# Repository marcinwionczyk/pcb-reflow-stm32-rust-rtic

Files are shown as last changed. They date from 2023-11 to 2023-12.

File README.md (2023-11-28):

# pcb-reflow-stm32-rust-rtic
This is how the reflow process look like:
https://youtu.be/pWV79pceqmc?si=kS1UuS4xw2wpDsws

## Software

Rust code for STM32F411RCT6 microcontroller to drive PCB reflow solder plate.
Code is based on https://github.com/gabrielvegamotta/PCB-Reflow/blob/main/V1-Arduino-PTH/Firmware/PCB_Reflow_V1.6.ino

Base of the code was generated with command: 
`cargo generate --git https://github.com/burrbull/stm32-template/`

In order to build it, you need to prepare your environment according to:
https://docs.rust-embedded.org/book/intro/install.html

and issue a command within this folder:
- `cargo build --release` for release version
- `cargo build` for unoptimised, debug version

Then you may run software on microcontroller with `cargo run` and flash it via STLink device with 
`cargo flash --release --chip STM32F411RCT6x`  
## Hardware
This is how the PCB top layer look like:
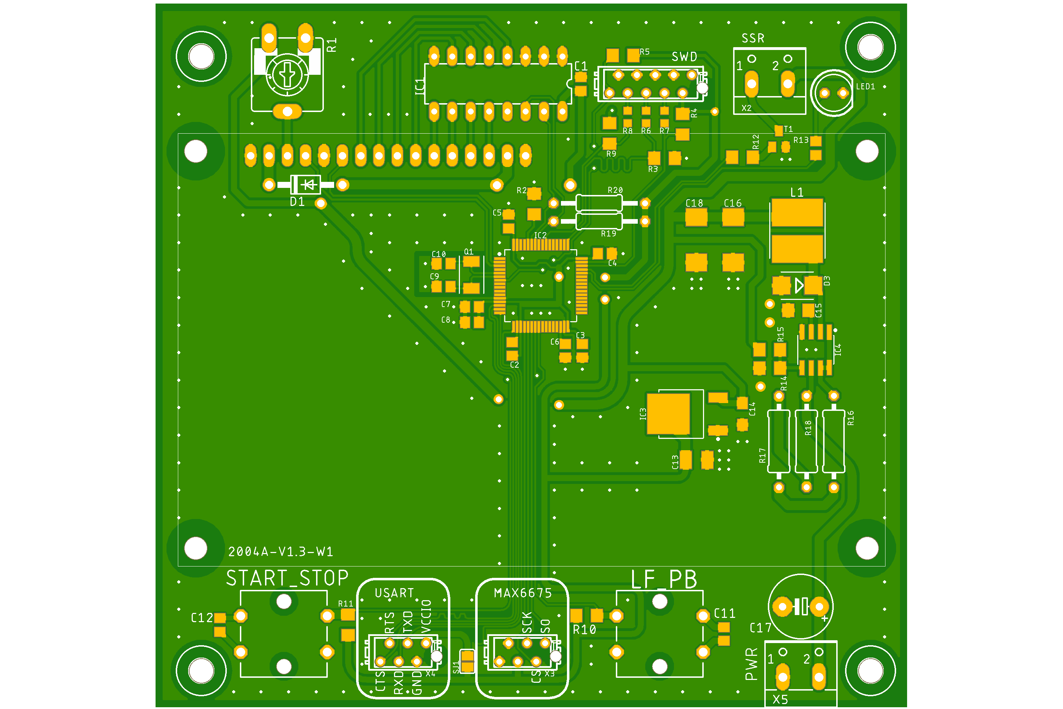
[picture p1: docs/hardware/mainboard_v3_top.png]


Here you have [schematics in PDF](./docs/hardware/mainboard_v3.pdf)

Some major parts:
1. MAX6675 as a temperature sensor. You can get it for example from here:
https://botland.store/high-precision-temperature-sensors/12504-max6675-thermocouple-spi-temperature-sensor-5904422307868.html
2. TC2004A LCD Character screen: https://botland.store/alphanumeric-and-graphic-displays/19736-lcd-display-4x20-characters-green-with-connectors-justpi-5903351243087.html
3. PCF8574 as I2C port expander
4. SWT-11136 buttons: https://botland.store/tact-switch/11138-tact-switch-12x12mm-cap-black-5-pieces-5904422307530.html
5. 
6. micromatch connectors (I have plenty of them)

PCB was designed with Autodesk EAGLE. 
- [schematics](./docs/hardware/mainboard_v3.sch)
- [PCB project](./docs/hardware/mainboard_v3.brd)

I power it with +12V DC.
If you want to order a PCB, here you have [gerber files](./docs/hardware/mainboard_v3_2023-11-27.zip)

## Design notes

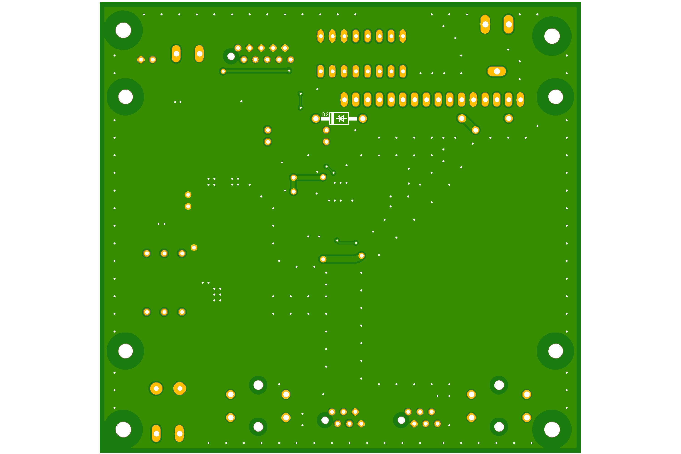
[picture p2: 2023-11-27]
docs/hardware/mainboard_v3_bottom.png

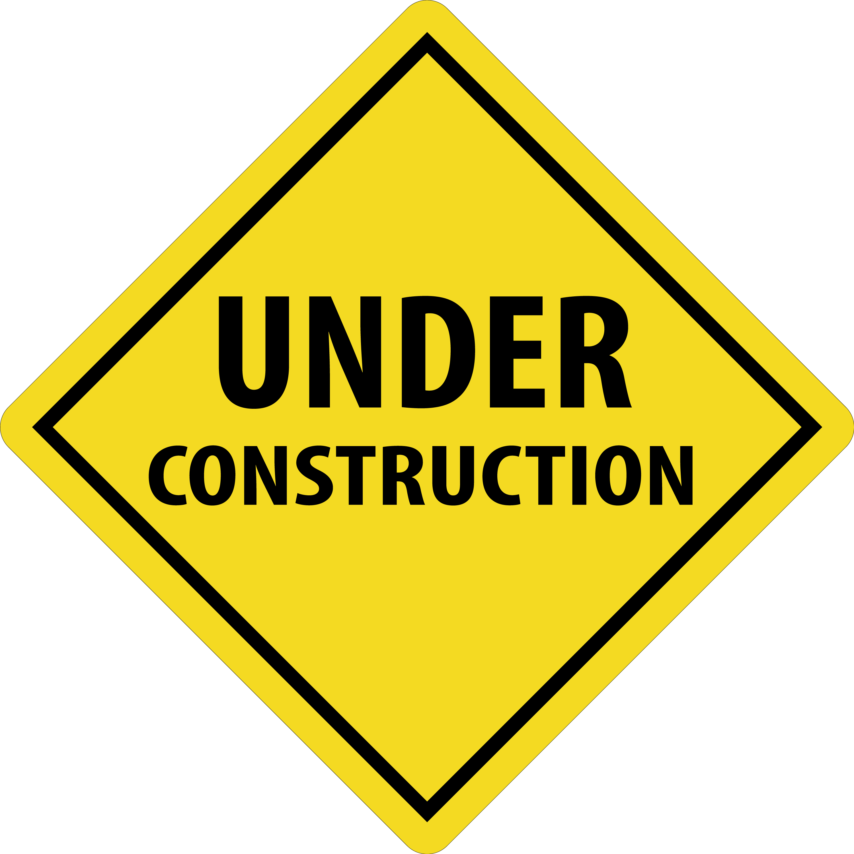
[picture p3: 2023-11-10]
docs/images/vectorstock_19719079.png

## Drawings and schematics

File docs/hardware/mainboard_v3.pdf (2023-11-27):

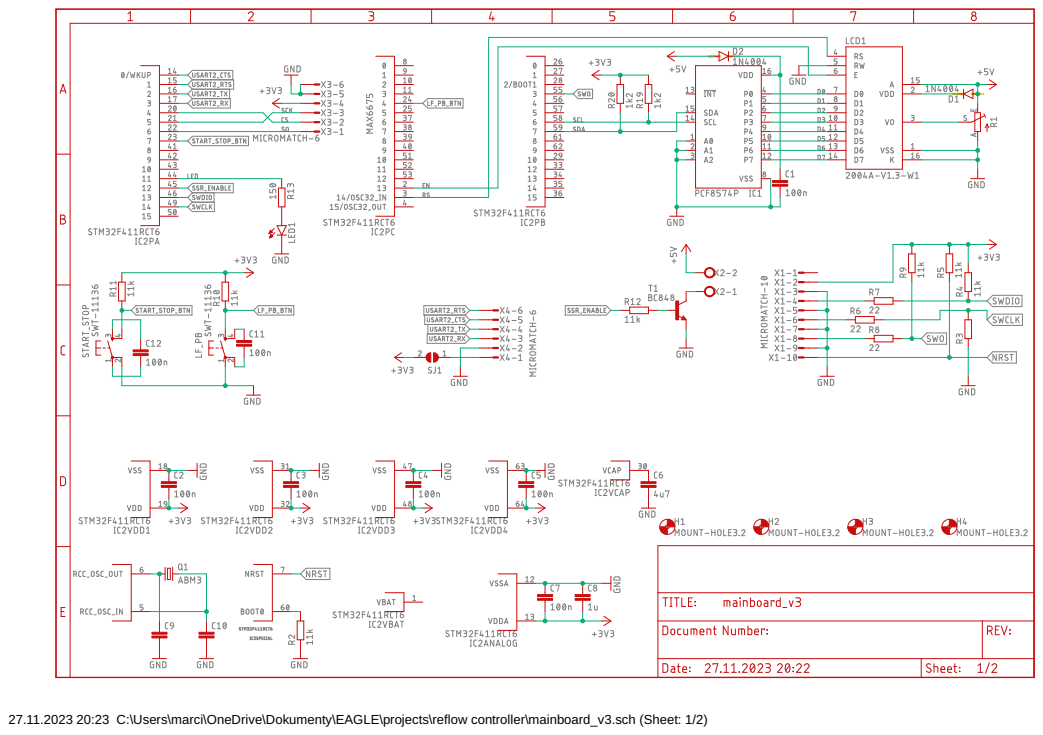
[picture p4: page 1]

27.11.2023 20:23 C:\Users\marci\OneDrive\Dokumenty\EAGLE\projects\reflow controller\mainboard_v3.sch (Sheet: 1/2)

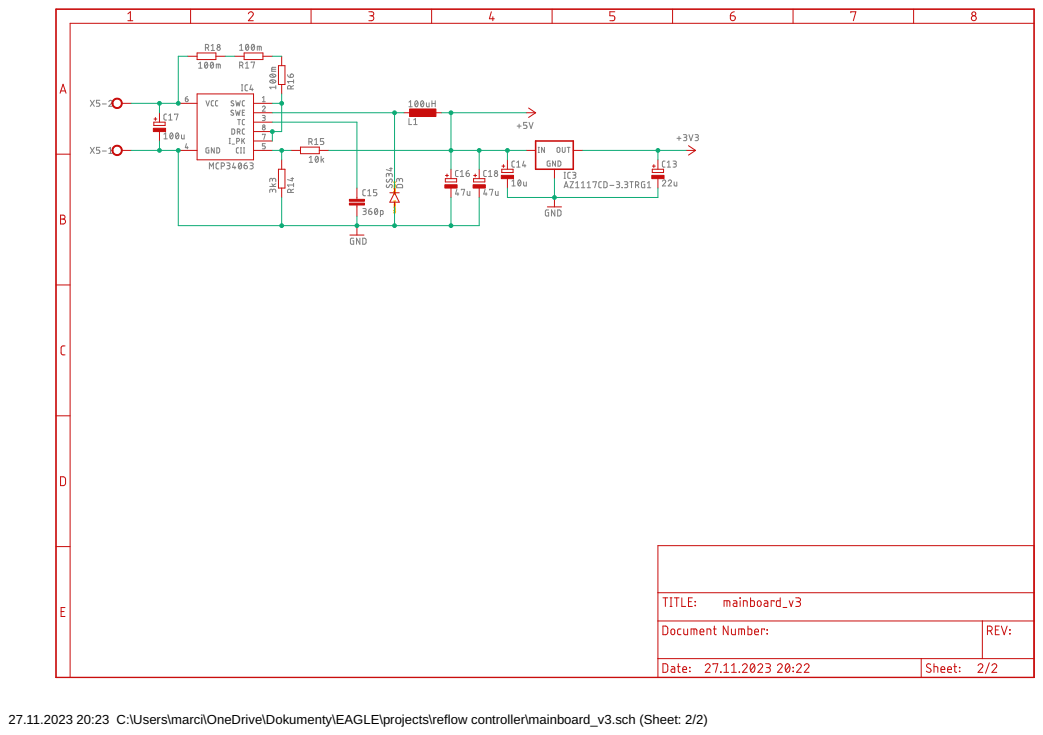
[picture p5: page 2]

27.11.2023 20:23 C:\Users\marci\OneDrive\Dokumenty\EAGLE\projects\reflow controller\mainboard_v3.sch (Sheet: 2/2)

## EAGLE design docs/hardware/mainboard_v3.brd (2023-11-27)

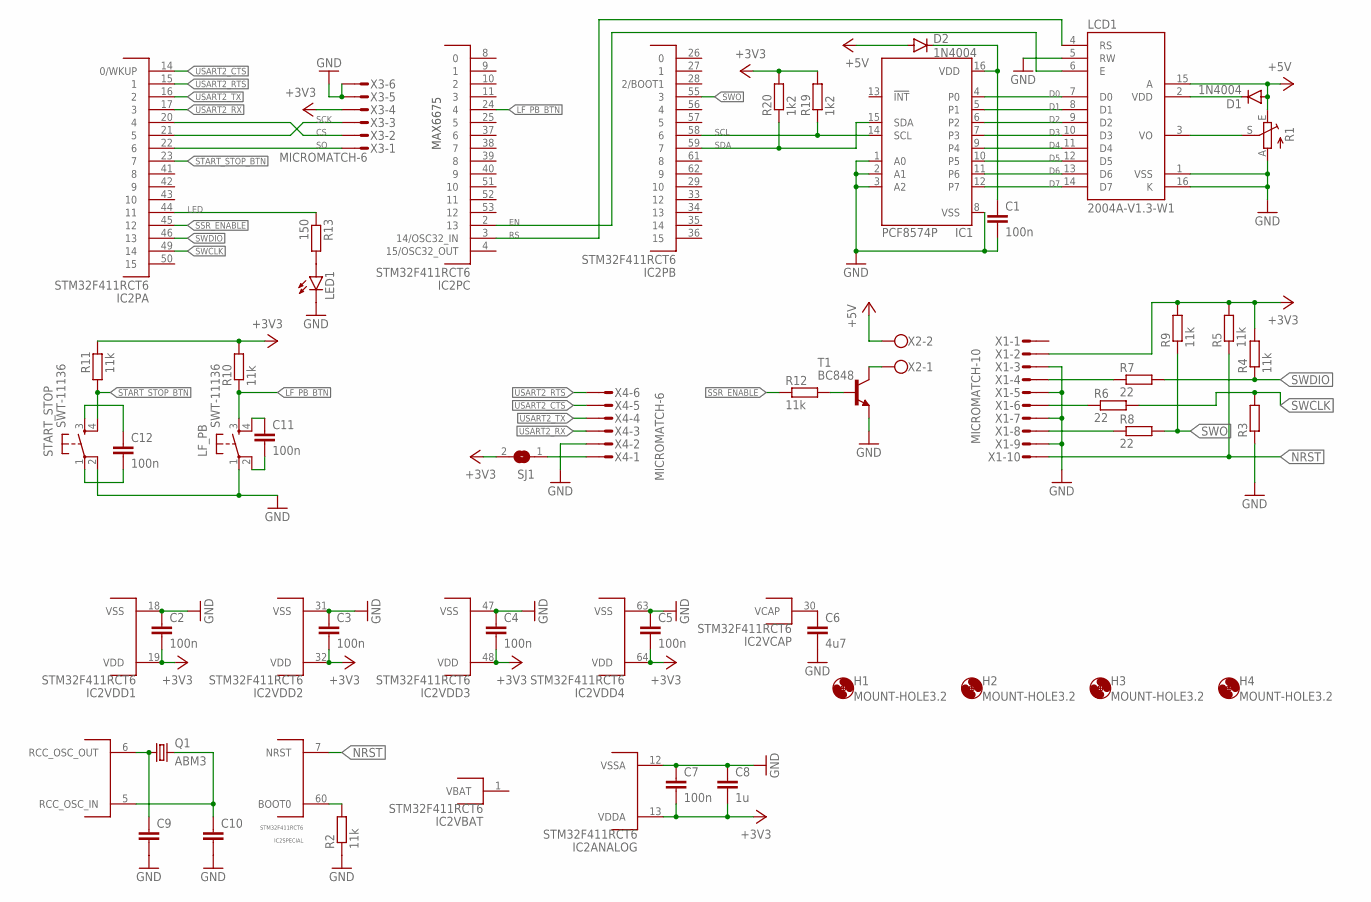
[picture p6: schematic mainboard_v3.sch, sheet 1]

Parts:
C1, C2, C3, C4, C5, C7, C11, C12: 100n; C0805
C6: 4u7; C0805
C8: 1u; C0805
C9, C10: C-EUC0805; C0805
D1, D2: 1N4004; DO41-10
H1, H2, H3, H4: MOUNT-HOLE3.2; 3,2
IC1: PCF8574P; DIL16
IC2: STM32F411RCT6; QFP50P1200X1200X160-64N
LCD1: 2004A-V1.3-W1
LED1: LED5MM
LF_PB: SWT-11136
Q1: ABM3; XTALDFN500X320X130-2N
R1: TRIM_EU-CA9V; CA9V
R2, R4, R5, R9, R10, R11, R12: 11k; R1206
R3: R-EU_R1206; R1206
R6, R7, R8: 22; R0603
R13: 150; R0805
R19, R20: 1k2; 0207/12
SJ1: SJ
START_STOP: SWT-11136
T1: BC848; SOT23
X1: MICROMATCH-10
X2: W237-102
X3, X4: MICROMATCH-6

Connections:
2: IC2.54 (2)
+3V3: C2.2, C3.2, C4.2, C5.2, C7.2, C8.2, IC2.13 (VDDA), IC2.19 (VDD), IC2.32 (VDD), IC2.48 (VDD), IC2.64 (VDD), R4.2, R5.2, R9.2, R10.2, R11.2, R19.2, R20.2, SJ1.2, X1.2, X3.4; also elsewhere on the board
+5V: D1.A, D2.A, LCD1.15 (A), R1.E, X2.2; also elsewhere on the board
CS: IC2.20 (4), X3.2
D0: IC1.4 (P0), LCD1.7 (D0)
D1: IC1.5 (P1), LCD1.8 (D1)
D2: IC1.6 (P2), LCD1.9 (D2)
D3: IC1.7 (P3), LCD1.10 (D3)
D4: IC1.9 (P4), LCD1.11 (D4)
D5: IC1.10 (P5), LCD1.12 (D5)
D6: IC1.11 (P6), LCD1.13 (D6)
D7: IC1.12 (P7), LCD1.14 (D7)
EN: IC2.2 (13), LCD1.6 (E)
GND: C1.2, C2.1, C3.1, C4.1, C5.1, C6.2, C7.1, C8.1, C9.2, C10.2, IC1.1 (A0), IC1.2 (A1), IC1.3 (A2), IC1.8 (VSS), IC2.12 (VSSA), IC2.18 (VSS), IC2.31 (VSS), IC2.47 (VSS), IC2.63 (VSS), LCD1.1 (VSS), LCD1.5 (RW), LCD1.16 (K), LED1.K (C), LF_PB.1, R1.A, R2.1, R3.1, START_STOP.2 (P1), T1.2 (E), X1.3, X1.5, X1.7, X1.9, X3.5, X3.6, X4.2; also elsewhere on the board
LED: IC2.44 (11), R13.1
LF_PB_BTN: IC2.24 (4), LF_PB.3 (S), R10.1
unnamed: IC2.60 (BOOT0), R2.2
unnamed: C1.1, D2.C, IC1.16 (VDD)
unnamed: C10.1, IC2.5 (RCC_OSC_IN), Q1.2
unnamed: C9.1, IC2.6 (RCC_OSC_OUT), Q1.1
unnamed: R7.1, X1.4
unnamed: R6.1, X1.6
unnamed: R8.1, X1.8
unnamed: LCD1.3 (VO), R1.S
unnamed: C6.1, IC2.30 (VCAP)
unnamed: T1.3 (C), X2.1
unnamed: R12.2, T1.1 (B)
unnamed: LED1.A, R13.2
unnamed: C12.2, START_STOP.1
unnamed: C11.2, LF_PB.2 (P1)
unnamed: C11.1, LF_PB.4 (S1)
unnamed: C12.1, START_STOP.3 (S)
unnamed: D1.C, LCD1.2 (VDD)
unnamed: SJ1.1, X4.1
NRST: IC2.7 (NRST), R5.1, X1.10
RS: IC2.3 (14/OSC32_IN), LCD1.4 (RS)
SCK: IC2.21 (5), X3.3
SCL: IC1.14 (SCL), IC2.58 (6), R19.1
SDA: IC1.15 (SDA), IC2.59 (7), R20.1
SO: IC2.22 (6), X3.1
SSR_ENABLE: IC2.45 (12), R12.1
START_STOP_BTN: IC2.23 (7), R11.1, START_STOP.4 (S1)
SWCLK: IC2.49 (14), R3.2, R6.2
SWDIO: IC2.46 (13), R4.1, R7.2
SWO: IC2.55 (3), R8.2, R9.1
USART2_CTS: IC2.14 (0/WKUP), X4.5
USART2_RTS: IC2.15 (1), X4.6
USART2_RX: IC2.17 (3), X4.3
USART2_TX: IC2.16 (2), X4.4
VBAT: IC2.1 (VBAT)

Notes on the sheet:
MAX6675

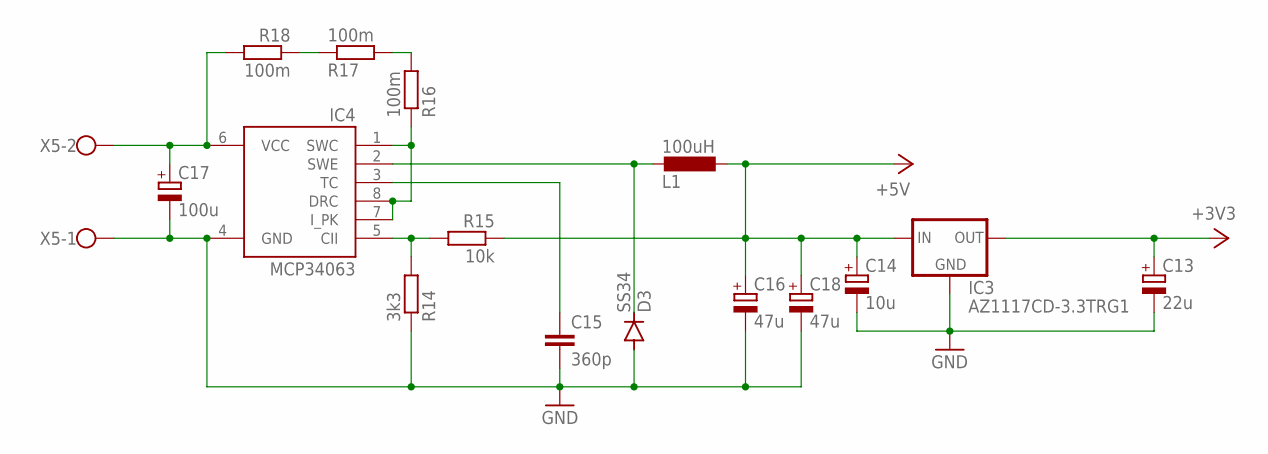
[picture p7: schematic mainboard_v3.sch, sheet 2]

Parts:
C13: 22u; SMC_B
C14: 10u; SMC_A
C15: 360p; C1206
C16, C18: 47u; SMC_D
C17: 100u; E5-8,5
D3: SS34; SMB
IC3: AZ1117CD-3.3TRG1; TO228P1014X240-3N
IC4: MCP34063; SOIC127P600X175-8N
L1: 100uH; INDM7770X500N
R14: 3k3; R1206
R15: 10k; R1206
R16, R17, R18: 100m; 0309/12
X5: W237-102

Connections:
+3V3: C13.+, IC3.3 (OUT); also elsewhere on the board
+5V: C14.+, C16.+, C18.+, IC3.2 (IN), L1.1, R15.1; also elsewhere on the board
GND: C13.-, C14.-, C15.2, C16.-, C17.-, C18.-, D3.A, IC3.1 (GND), IC4.4 (GND), R14.1, X5.1; also elsewhere on the board
unnamed: IC4.1 (SWC), IC4.7 (I_PK), IC4.8 (DRC), R16.1
unnamed: C15.1, IC4.3 (TC)
unnamed: D3.C, IC4.2 (SWE), L1.2
unnamed: IC4.5 (CII), R14.2, R15.2
unnamed: R16.2, R17.2
unnamed: R17.1, R18.1
unnamed: C17.+, IC4.6 (VCC), R18.2, X5.2

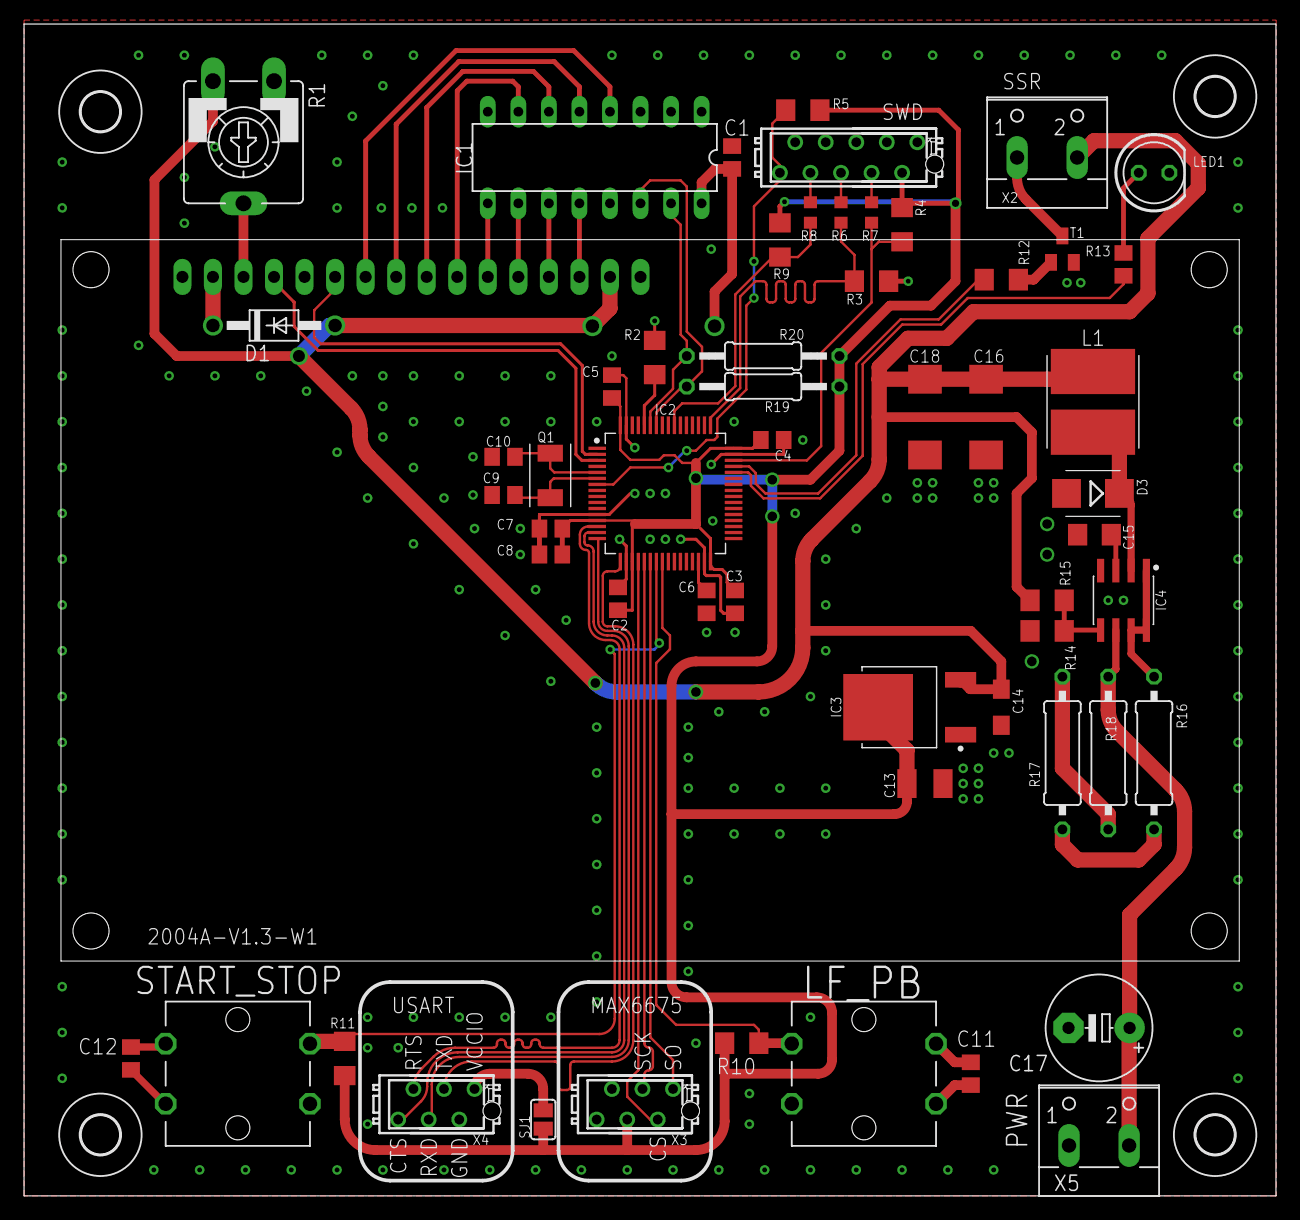
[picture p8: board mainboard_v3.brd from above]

Board: 2 copper layers, 104.1 x 97.5 mm, 62 parts (1 on the bottom side), 55 nets.

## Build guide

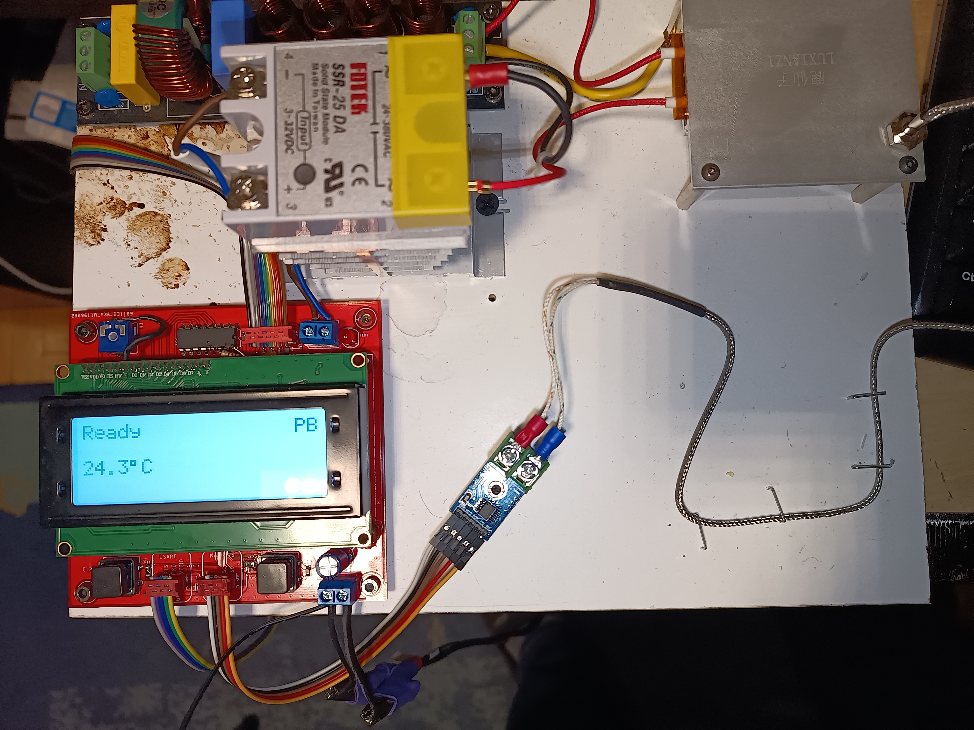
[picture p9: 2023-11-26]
docs/images/setup.jpg

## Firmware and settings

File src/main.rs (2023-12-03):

#![deny(unsafe_code)]
#![no_main]
#![no_std]

mod display;

// Print panic message to probe console
use panic_probe as _;
use defmt_rtt as _;


#[rtic::app(device = pac, peripherals = true, dispatchers = [EXTI1, EXTI2])]
mod app {
    use crate::display::{TC2004ADriver};
    use embedded_hal::spi::MODE_0;
    use fugit::MicrosDurationU32;
    use stm32f4xx_hal::{
        gpio::{Edge, Input, Output, Pin,
               PA4, PA7, PA11, PA12,
               PB8,
               PC4},
        prelude::*,
        pac,
        i2c,
        timer::MonoTimerUs,
    };
    use stm32f4xx_hal::gpio::{NoPin, Speed};
    use stm32f4xx_hal::i2c::I2c;
    use stm32f4xx_hal::pac::{I2C1, SPI1, TIM5};
    use stm32f4xx_hal::spi::Spi;
    use stm32f4xx_hal::timer::DelayUs;
    use pid::*;
    use ufmt::uwrite;
    use ufmt_float::uFmt_f32;
    use micromath::F32;
    use heapless::String;

    #[derive(PartialEq, Clone, Copy)]
    enum SwitchEnum { None, One, Two }

    #[derive(PartialEq)]
    enum ReflowProfileEnum { LeadFree, Leaded }

    #[derive(PartialEq, Clone, Copy)]
    enum ReflowStateEnum { Idle, Preheat, Soak, Reflow, Cool, Complete, TooHot }

    #[derive(PartialEq)]
    enum ReflowStatusEnum { Off, On }

    // General Profile Constants
    const TEMPERATURE_ROOM: f32 = 50.0;
    const TEMPERATURE_SOAK_MIN: f32 = 150.0;
    const TEMPERATURE_COOL_MIN: f32 = 100.0;
    const SOAK_TEMPERATURE_STEP: f32 = 5.0;

    // Lead free profile constants
    const TEMPERATURE_SOAK_MAX_LF: f32 = 200.0;
    const TEMPERATURE_REFLOW_MAX_LF: f32 = 250.0;
    const SOAK_MICRO_PERIOD_LF: u32 = 9000;

    // Leaded profile constants
    const TEMPERATURE_SOAK_MAX_PB: f32 = 180.0;
    const TEMPERATURE_REFLOW_MAX_PB: f32 = 224.0;
    const SOAK_MICRO_PERIOD_PB: u32 = 10000;

    // PID parameters
    const PID_KP_PREHEAT: f32 = 100.0;
    const PID_KI_PREHEAT: f32 = 0.025;
    const PID_KD_PREHEAT: f32 = 20.0;
    const PID_KP_SOAK: f32 = 300.0;
    const PID_KI_SOAK: f32 = 0.05;
    const PID_KD_SOAK: f32 = 250.0;
    const PID_KP_REFLOW: f32 = 300.0;
    const PID_KI_REFLOW: f32 = 0.05;
    const PID_KD_REFLOW: f32 = 350.0;

    const LCD_MESSAGES_REFLOW_STATUS: &'static [&'static str] = &["Ready", "Preheat", "Soak", "Reflow", "Cool", "Done!", "Hot!", "Error"];

    // A monotonic timer to enable scheduling in RTIC
    #[monotonic(binds = TIM2, default = true)]
    type MilisecMono = MonoTimerUs<pac::TIM2>; // 100 Hz / 10 ms granularity

    #[shared]
    struct Shared {
        start_stop_pressed: bool,
        lf_pb_pressed: bool,
        pcf8574_interrupted: bool,
        temp: F32,
    }

    // Local resources go here
    #[local]
    struct Local {
        start_stop_button: PA7<Input>,
        lf_pb_button: PC4<Input>,
        pcf8574_int_pin: PB8<Input>,
        ssr_pin: PA12<Output>,
        led_pin: PA11<Output>,
        cs_pin: PA4<Output>,
        spi: Spi<SPI1, false, u16>,
        display: TC2004ADriver<Pin<'C', 14, Output>, Pin<'C', 13, Output>, DelayUs<TIM5>, I2c<I2C1>>,
    }

    #[init]
    fn init(mut ctx: init::Context) -> (Shared, Local, init::Monotonics) {
        let mut syscfg = ctx.device.SYSCFG.constrain();
        let rcc = ctx.device.RCC.constrain();
        let clocks = rcc.cfgr.use_hse(8.MHz()).sysclk(48.MHz()).freeze();
        let mono = ctx.device.TIM2.monotonic_us(&clocks);
        let gpioa = ctx.device.GPIOA.split();
        let gpiob = ctx.device.GPIOB.split();
        let gpioc = ctx.device.GPIOC.split();

        let mut pcf8574_int_pin = gpiob.pb8.into_pull_up_input();
        pcf8574_int_pin.make_interrupt_source(&mut syscfg);
        pcf8574_int_pin.enable_interrupt(&mut ctx.device.EXTI);
        pcf8574_int_pin.trigger_on_edge(&mut ctx.device.EXTI, Edge::Falling);

        let mut start_stop_button = gpioa.pa7.into_floating_input();
        start_stop_button.make_interrupt_source(&mut syscfg);
        start_stop_button.enable_interrupt(&mut ctx.device.EXTI);
        start_stop_button.trigger_on_edge(&mut ctx.device.EXTI, Edge::Falling);

        let mut lf_pb_button = gpioc.pc4.into_floating_input();
        lf_pb_button.make_interrupt_source(&mut syscfg);
        lf_pb_button.enable_interrupt(&mut ctx.device.EXTI);
        lf_pb_button.trigger_on_edge(&mut ctx.device.EXTI, Edge::Falling);

        let mut ssr_pin = gpioa.pa12.into_push_pull_output().speed(Speed::VeryHigh);
        ssr_pin.set_low();
        let mut led_pin = gpioa.pa11.into_push_pull_output();
        led_pin.set_high();
        let mut cs_pin = gpioa.pa4.into_push_pull_output();
        cs_pin.set_high();

        let sck = gpioa.pa5.into_alternate::<5>().speed(Speed::VeryHigh);
        let miso = gpioa.pa6.into_alternate().speed(Speed::VeryHigh);
        let no_mosi = NoPin::new();
        let spi = ctx.device.SPI1.spi((sck, miso, no_mosi), MODE_0, 1.MHz(), &clocks).frame_size_16bit();

        let en_pin = gpioc.pc13.into_push_pull_output();
        let rs_pin = gpioc.pc14.into_push_pull_output();

        let scl = gpiob.pb6.into_alternate_open_drain();
        let sda = gpiob.pb7.into_alternate_open_drain();
        let i2c = ctx.device.I2C1.i2c((scl, sda),
                                      i2c::Mode::Standard { frequency: 50.kHz() },
                                      &clocks);
        let delay = ctx.device.TIM5.delay_us(&clocks);
        let mut display = TC2004ADriver::new(i2c, rs_pin, en_pin, delay).build();
        display.print("Not so tiny");
        display.set_position(0, 2);
        display.print("reflow controller");
        display.home();
        rtic::pend(pac::Interrupt::EXTI4);
        rtic::pend(pac::Interrupt::EXTI9_5);
        main::spawn_after(2.secs()).unwrap();
        defmt::info!("init done!");
        (
            Shared {
                start_stop_pressed: false,
                lf_pb_pressed: false,
                pcf8574_interrupted: false,
                temp: F32(0.0),
                // Initialization of shared resources go here
            },
            Local {
                start_stop_button,
                lf_pb_button,
                pcf8574_int_pin,
                ssr_pin,
                led_pin,
                cs_pin,
                spi,
                display,
                // Initialization of local resources go here
            },
            init::Monotonics(mono),
        )
    }

    #[task(priority = 3, binds = EXTI4, local = [lf_pb_button], shared = [lf_pb_pressed])]
    fn lf_pb_btn_click(mut ctx: lf_pb_btn_click::Context) {
        if ctx.local.lf_pb_button.check_interrupt() {
            ctx.local.lf_pb_button.clear_interrupt_pending_bit();
            ctx.shared.lf_pb_pressed.lock(|lf_pb_pressed| *lf_pb_pressed = true);
        }
    }

    #[task(priority = 3, binds = EXTI9_5, local = [start_stop_button, pcf8574_int_pin], shared = [start_stop_pressed, pcf8574_interrupted])]
    fn exti_9_5_interrupt(mut ctx: exti_9_5_interrupt::Context) {
        if ctx.local.start_stop_button.check_interrupt() {
            ctx.local.start_stop_button.clear_interrupt_pending_bit();
            ctx.shared.start_stop_pressed.lock(|start_stop_pressed| *start_stop_pressed = true);
        }
    }

    #[task(priority = 2, shared = [temp], local = [spi, cs_pin])]
    fn read_temp(mut ctx: read_temp::Context) {
        let mut spi_value: [u16; 1] = [0];
        ctx.local.cs_pin.set_low();
        ctx.local.spi.read(&mut spi_value).unwrap();
        ctx.local.cs_pin.set_high();

        let input_is_open = (spi_value[0] & 0x4) >> 2;
        let temp_part = F32(((spi_value[0] & 0x7FF8) >> 3) as f32);
        if input_is_open == 0 {
            ctx.shared.temp.lock(|temp| *temp = temp_part / 4.0);
        }
    }

    #[task(priority = 1, shared = [temp, start_stop_pressed, lf_pb_pressed], local = [display, ssr_pin, led_pin])]
    fn main(mut ctx: main::Context) {
        let mut reflow_state = ReflowStateEnum::Idle;
        let mut reflow_profile = ReflowProfileEnum::Leaded;
        let mut reflow_status = ReflowStatusEnum::Off;
        let mut temp_local: f32 = 0.0;
        let mut set_point: f32 = 0.0;
        let mut soak_temperature_max: f32 = 0.0;
        let mut reflow_temperature_max: f32 = 0.0;
        let mut soak_micro_period: MicrosDurationU32 = 0.micros();
        let mut pid: Pid<f32> = Pid::new(0.0, 0.0);
        let mut output: ControlOutput<f32> = ControlOutput { p: 0.0, i: 0.0, d: 0.0, output: 0.0 };
        let window_size: f32 = 2000.0;
        let mut next_check = monotonics::now();
        let mut next_read = monotonics::now();
        let mut update_lcd = monotonics::now();
        let mut window_start_time = monotonics::now();
        let mut timer_soak = monotonics::now();
        let mut switch_status = SwitchEnum::None;
        let mut ssr_counter: u8 = 0;

        loop {
            if monotonics::now() > next_read {
                next_read += 1.secs();
                read_temp::spawn().unwrap();
            }
            if monotonics::now() > next_check {
                next_check += 1.secs();
                match reflow_status {
                    ReflowStatusEnum::On => {
                        ctx.local.led_pin.toggle();
                        defmt::info!("{}, {}, {}", set_point, f32::from(temp_local), output.output);
                    }
                    ReflowStatusEnum::Off => {
                        ctx.local.led_pin.set_low()
                    }
                }
            }
            if monotonics::now() > update_lcd {
                // Update LCD in the next 100 ms
                update_lcd += 100.millis();
                // Clear LCD
                ctx.local.display.clear();
                // Print current system state
                ctx.local.display.print(LCD_MESSAGES_REFLOW_STATUS[reflow_state as usize]);
                ctx.local.display.set_position(18, 0);
                match reflow_profile {
                    ReflowProfileEnum::LeadFree => { ctx.local.display.print("LF"); }
                    ReflowProfileEnum::Leaded => { ctx.local.display.print("PB"); }
                }
                ctx.local.display.set_position(0, 2);
                ctx.shared.temp.lock(|temp| {
                    // temperature adjusting function
                    temp_local = f32::from(F32(-0.002634) * (*temp).powi(2) + (*temp).mul_add(F32(1.725721), F32(13.53099)));
                });
                let mut s: String<20> = String::new();
                let temp_write = uFmt_f32::One(temp_local as f32);
                uwrite!(&mut s, "{}", temp_write).unwrap();
                ctx.local.display.print(s.as_str());
                ctx.local.display.write(0xDF);
                ctx.local.display.write('C' as u8);
            }
            match reflow_state {
                ReflowStateEnum::Idle => {
                    if temp_local >= TEMPERATURE_ROOM {
                        reflow_state = ReflowStateEnum::TooHot;
                    } else {
                        if switch_status == SwitchEnum::One {
                            defmt::info!("Setpoint, Input, Output");
                            window_start_time = monotonics::now();
                            set_point = TEMPERATURE_SOAK_MIN;
                            match reflow_profile {
                                ReflowProfileEnum::LeadFree => {
                                    soak_temperature_max = TEMPERATURE_SOAK_MAX_LF;
                                    reflow_temperature_max = TEMPERATURE_REFLOW_MAX_LF;
                                    soak_micro_period = SOAK_MICRO_PERIOD_LF.micros();
                                }
                                ReflowProfileEnum::Leaded => {
                                    soak_temperature_max = TEMPERATURE_SOAK_MAX_PB;
                                    reflow_temperature_max = TEMPERATURE_REFLOW_MAX_PB;
                                    soak_micro_period = SOAK_MICRO_PERIOD_PB.micros();
                                }
                            }
                            pid = Pid::new(set_point, window_size);
                            defmt::debug!("pid created: {}", pid);
                            pid.p(PID_KP_PREHEAT, window_size)
                                .d(PID_KD_PREHEAT, window_size)
                                .i(PID_KI_PREHEAT, window_size);
                            reflow_state = ReflowStateEnum::Preheat;
                        }
                    }
                }
                ReflowStateEnum::Preheat => {
                    reflow_status = ReflowStatusEnum::On;
                    if temp_local > TEMPERATURE_SOAK_MIN {
                        timer_soak = monotonics::now() + soak_micro_period;
                        pid.p(PID_KP_SOAK, window_size)
                            .i(PID_KI_SOAK, window_size)
                            .d(PID_KD_SOAK, window_size)
                            .setpoint(TEMPERATURE_SOAK_MIN + SOAK_TEMPERATURE_STEP);
                        reflow_state = ReflowStateEnum::Soak;
                    }
                }
                ReflowStateEnum::Soak => {
                    if monotonics::now() > timer_soak {
                        timer_soak = monotonics::now() + soak_micro_period;
                        set_point += SOAK_TEMPERATURE_STEP;
                        if set_point > soak_temperature_max {
                            pid.p(PID_KP_REFLOW, window_size)
                                .i(PID_KI_REFLOW, window_size)
                                .d(PID_KD_REFLOW, window_size)
                                .setpoint(reflow_temperature_max);
                            reflow_state = ReflowStateEnum::Reflow;
                        }
                    }
                }
                ReflowStateEnum::Reflow => {
                    if temp_local >= (reflow_temperature_max - 5.0) {
                        pid.p(PID_KP_REFLOW, window_size)
                        .i(PID_KI_REFLOW, window_size)
                        .d(PID_KD_REFLOW, window_size)
                        .setpoint(TEMPERATURE_COOL_MIN);
                        reflow_state = ReflowStateEnum::Cool;
                    }
                }
                ReflowStateEnum::Cool => {
                    reflow_status = ReflowStatusEnum::Off;
                    reflow_state = ReflowStateEnum::Complete;
                }
                ReflowStateEnum::Complete => {
                    reflow_state = ReflowStateEnum::Idle;
                }
                ReflowStateEnum::TooHot => {
                    if temp_local < TEMPERATURE_ROOM {
                        reflow_state = ReflowStateEnum::Idle;
                    }
                }
            }
            match switch_status {
                SwitchEnum::None => {}
                SwitchEnum::One => {
                    if reflow_status == ReflowStatusEnum::On {
                        reflow_status = ReflowStatusEnum::Off;
                        reflow_state = ReflowStateEnum::Idle;
                    }
                }
                SwitchEnum::Two => {
                    if reflow_state == ReflowStateEnum::Idle {
                        match reflow_profile {
                            ReflowProfileEnum::LeadFree => {
                                reflow_profile = ReflowProfileEnum::Leaded;
                            }
                            ReflowProfileEnum::Leaded => {
                                reflow_profile = ReflowProfileEnum::LeadFree;
                            }
                        }
                    }
                }
            }
            switch_status = SwitchEnum::None;
            ctx.shared.start_stop_pressed.lock(|pressed| {
                if *pressed {
                    switch_status = SwitchEnum::One;
                    *pressed = false;
                }
            });
            ctx.shared.lf_pb_pressed.lock(|pressed| {
                if *pressed {
                    switch_status = SwitchEnum::Two;
                    *pressed = false;
                }
            });
            if reflow_status == ReflowStatusEnum::On {
                let now = monotonics::now();
                output = pid.next_control_output(temp_local as f32);
                if (now - window_start_time) > (window_size as u32).millis::<1, 1_000_000>() {
                    window_start_time += (window_size as u32).millis::<1, 1_000_000>();
                }
                if (output.output as u32).millis::<1, 1_000_000>() > (now - window_start_time) {
                    defmt::debug!("setting ssr pin high");
                    // ssr_counter is to slow down heating process
                    ssr_counter += 1;
                    if ssr_counter > 5 {
                        ctx.local.ssr_pin.set_high();
                        ssr_counter = 0;
                    } else {
                        ctx.local.ssr_pin.set_low();
                    }
                } else {
                    ctx.local.ssr_pin.set_low();
                }
            }
        }
    }
}

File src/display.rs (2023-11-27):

use stm32f4xx_hal::hal::blocking::delay::DelayUs;
use stm32f4xx_hal::hal::blocking::i2c::{Write, WriteRead};
use stm32f4xx_hal::hal::digital::v2::OutputPin;


#[repr(u8)]
#[allow(dead_code)]
enum Command {
    ClearDisplay = 0x01,
    ReturnHome = 0x02,
    EntryModeSet = 0x04, // 1 I/D S. Assign cursor moving direction and enable shift of the entire display
    DisplayControl = 0x08, // 1 D C B. Set display (D), cursor (C), and blinking of cursor (B) on/off bit
    CursorShift = 0x10, // 1 S/C R/L - -. Set cursor moving and display shift control bit, and the direction
    FunctionSet = 0x20, // 1 DL N F - -. Set interface datalength (DL: 8-bit/4-bit), numbers of display line (N: 2-line/1-line
    SetCGramAddr = 0x40,
    // LCD_SETCGRAMADDR
    SetDDRAMAddr = 0x80,   // LCD_SETDDRAMADDR
}


#[repr(u8)]
#[allow(dead_code)]
enum Move {
    Display = 0x08,
    // LCD_DISPLAYMOVE
    Cursor = 0x00,  // LCD_CURSORMOVE
}

/// Flag that controls text direction
#[repr(u8)]
pub enum Entry {
    /// Text runs from right to left
    Right = 0x00, // LCD_ENTRYRIGHT

    /// Text runs from left to right (default)
    Left = 0x02, // LCD_ENTRYLEFT
}

/// Flag that sets the display to autoscroll
#[repr(u8)]
pub enum EntryShift {
    /// Turn AutoScroll on
    Increment = 0x01, // LCD_ENTRYSHIFTINCREMENT

    /// Turn AutoScroll off (default)
    Decrement = 0x00, // LCD_ENTRYSHIFTDECREMENT
}


/// Flag that sets the display on/off
#[repr(u8)]
pub enum Display {
    /// Turn Display on (default)
    On = 0x04, // LCD_DISPLAYON

    /// Turn Display off
    Off = 0x00, // LCD_DISPLAYOFF
}

/// Flag that sets the cursor on/off
#[repr(u8)]
pub enum Cursor {
    /// Turn Cursor on
    On = 0x02, // LCD_CURSORON

    /// Turn Cursor off
    Off = 0x00, // LCD_CURSOROFF
}

/// Flag that sets cursor background to blink
#[repr(u8)]
pub enum Blink {
    /// Turn Blink on
    On = 0x01, // LCD_BLINKON

    /// Turn Blink off (default)
    Off = 0x00, // LCD_BLINKOFF
}

/// Flag used to indicate direction for display scrolling
#[repr(u8)]
pub enum Scroll {
    /// Scroll display right
    Right = 0x04, // LCD_MOVERIGHT

    /// Scroll display left
    Left = 0x00, // LCD_MOVELEFT
}

/// Flag for the bus mode of the display
#[repr(u8)]
pub enum Mode {
    /// Use eight-bit bus (Set by [with_full_bus][LcdDisplay::with_full_bus])
    EightBits = 0x10, // LCD_8BITMODE
}

/// Flag for the number of lines in the display
#[repr(u8)]
pub enum Lines {
    /// Use four lines if available
    ///
    /// ## Notes
    /// Since HD44780 doesn't support 4-line LCDs, 4-line display is used like a 2-line display,
    /// but half of the characters were moved below the top part. Since the interface only allows
    /// two states for amount of lines: two and one, a way to differentiate between four line and
    /// two line mode is needed. According to HHD44780 documentation, when two-line display mode is
    /// used, the bit that specifies font size is ignored. Because of that, we can use it to
    /// differentiate between four line mode and two line mode.
    //OneLine = 0x00,
    //TwoLines = 0x08,
    FourLines = 0x0C,
}

/// One of the most popular sizes for this kind of LCD is 16x2
const DEFAULT_COLS: u8 = 20;

const DEFAULT_DISPLAY_FUNC: u8 = Mode::EightBits as u8 | Lines::FourLines as u8;
const DEFAULT_DISPLAY_CTRL: u8 = Display::On as u8 | Cursor::Off as u8 | Blink::Off as u8;
const DEFAULT_DISPLAY_MODE: u8 = Entry::Left as u8 | EntryShift::Decrement as u8;

const CMD_DELAY: u32 = 3500;
const CHR_DELAY: u32 = 450;
const I2C_ADDR: u8 = 0x20;

pub struct TC2004ADriver<RS, EN, D, I> {
    i2c: I,
    rs_pin: RS,
    en_pin: EN,
    delay: D,
    display_func: u8,
    display_mode: u8,
    display_ctrl: u8,
    offsets: [u8; 4]
}

impl<RS, EN, D, I> TC2004ADriver<RS, EN, D, I> where
    RS: OutputPin, EN: OutputPin, I: Write + WriteRead, D: DelayUs<u32>  {
    pub fn new(i2c: I, rs_pin: RS, en_pin: EN, delay_us: D) -> Self {
        TC2004ADriver {
            i2c,
            rs_pin,
            en_pin,
            delay: delay_us,
            display_func: DEFAULT_DISPLAY_FUNC,
            display_mode: DEFAULT_DISPLAY_MODE,
            display_ctrl: DEFAULT_DISPLAY_CTRL,
            offsets: [0x00, 0x40, 0x00 + DEFAULT_COLS, 0x40 + DEFAULT_COLS]
        }
    }

    pub fn send_instruction(&mut self, instruction: u8) {
        self.rs_pin.set_low().ok();
        self.delay.delay_us(10);
        self.i2c.write(I2C_ADDR, &[instruction]).ok();
        self.delay.delay_us(10);
        self.en_pin.set_high().ok();
        self.delay.delay_us(10);
        self.en_pin.set_low().ok();
    }

    pub fn send_data(&mut self, value: u8) {
        self.rs_pin.set_high().ok();
        self.delay.delay_us(10);
        self.i2c.write(I2C_ADDR, &[value]).ok();
        self.delay.delay_us(10);
        self.en_pin.set_high().ok();
        self.delay.delay_us(10);
        self.en_pin.set_low().ok();
    }

    pub fn build(mut self) -> Self {
        self.delay.delay_us(100000);
        self.rs_pin.set_low().ok();
        self.en_pin.set_low().ok();
        // this is according to the hitachi HD44780 datasheet
        // page 45 figure 23

        // Send function set command sequence
        self.i2c.write(I2C_ADDR, &[Command::FunctionSet as u8 | self.display_func]).ok();
        self.delay.delay_us(4500);  // wait for mare than 4.1 ms
        // second try
        self.i2c.write(I2C_ADDR, &[Command::FunctionSet as u8 | self.display_func]).ok();
        self.delay.delay_us(150);
        // third go
        self.i2c.write(I2C_ADDR, &[Command::FunctionSet as u8 | self.display_func]).ok();
        self.delay.delay_us(150);
        // finally set
        self.i2c.write(I2C_ADDR, &[Command::FunctionSet as u8 | self.display_func]).ok();
        self.delay.delay_us(60);
        self.display_on();
        self.clear();
        self.home();
        defmt::info!("display initiated");
        self
    }

    pub fn clear(&mut self) {
        self.send_instruction(Command::ClearDisplay as u8);
        self.delay.delay_us(CMD_DELAY);
    }

    pub fn home(&mut self) {
        self.send_instruction(Command::ReturnHome as u8);
        self.delay.delay_us(CMD_DELAY);
    }

    pub fn set_position(&mut self, col: u8, mut row: u8) {
        let max_lines = 4;
        let num_lines = 4;
        let mut pos = col;

        if row >= max_lines {
            row = max_lines.saturating_sub(1);
        }

        if row >= num_lines {
            row = num_lines.saturating_sub(1);
        }

        pos += self.offsets[row as usize];
        self.send_instruction(Command::SetDDRAMAddr as u8 | pos);
        self.delay.delay_us(CMD_DELAY);
    }

    pub fn set_scroll(&mut self, direction: Scroll, distance: u8) {
        let command = Command::CursorShift as u8 | Move::Display as u8 | direction as u8;
        for _ in 0..distance {
            self.send_instruction(command);
            self.delay.delay_us(CMD_DELAY);
        }
    }
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

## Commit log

2023-11-17 added reading temperature from MAX6675
2023-11-26 Display works. Buttons does not work.
    [display.rs, main.rs]
2023-11-26 buttons work
2023-11-27 final commit
    [mainboard_v3.brd, mainboard_v3.sch]
2023-11-27 fixed PID controller
2023-11-28 The PTC heater was heating to fast and I had to low temperature readings from thermocouple an MAX6675. Kind of solved it by togling ssr_pin instead of setting it high.
    [main.rs]
2023-12-01 - slowed down temperature rise of a heating element with ssr_counter variable - adjusted shown temperature with some correcting function (main.rs, line 264)
    [main.rs]
